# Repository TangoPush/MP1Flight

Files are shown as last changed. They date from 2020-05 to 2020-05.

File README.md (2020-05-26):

# MP1Flight

STM32MP1 based flight controller based off the Pixracer.

Slack channel available here:

https://join.slack.com/t/mp1flight/shared_invite/zt-ewtdxsr4-UjyOhen2aBG~TFt4L_m_wA

Current status:

Still working through developing the first PCB, please contribute at this stage with any features or changes.

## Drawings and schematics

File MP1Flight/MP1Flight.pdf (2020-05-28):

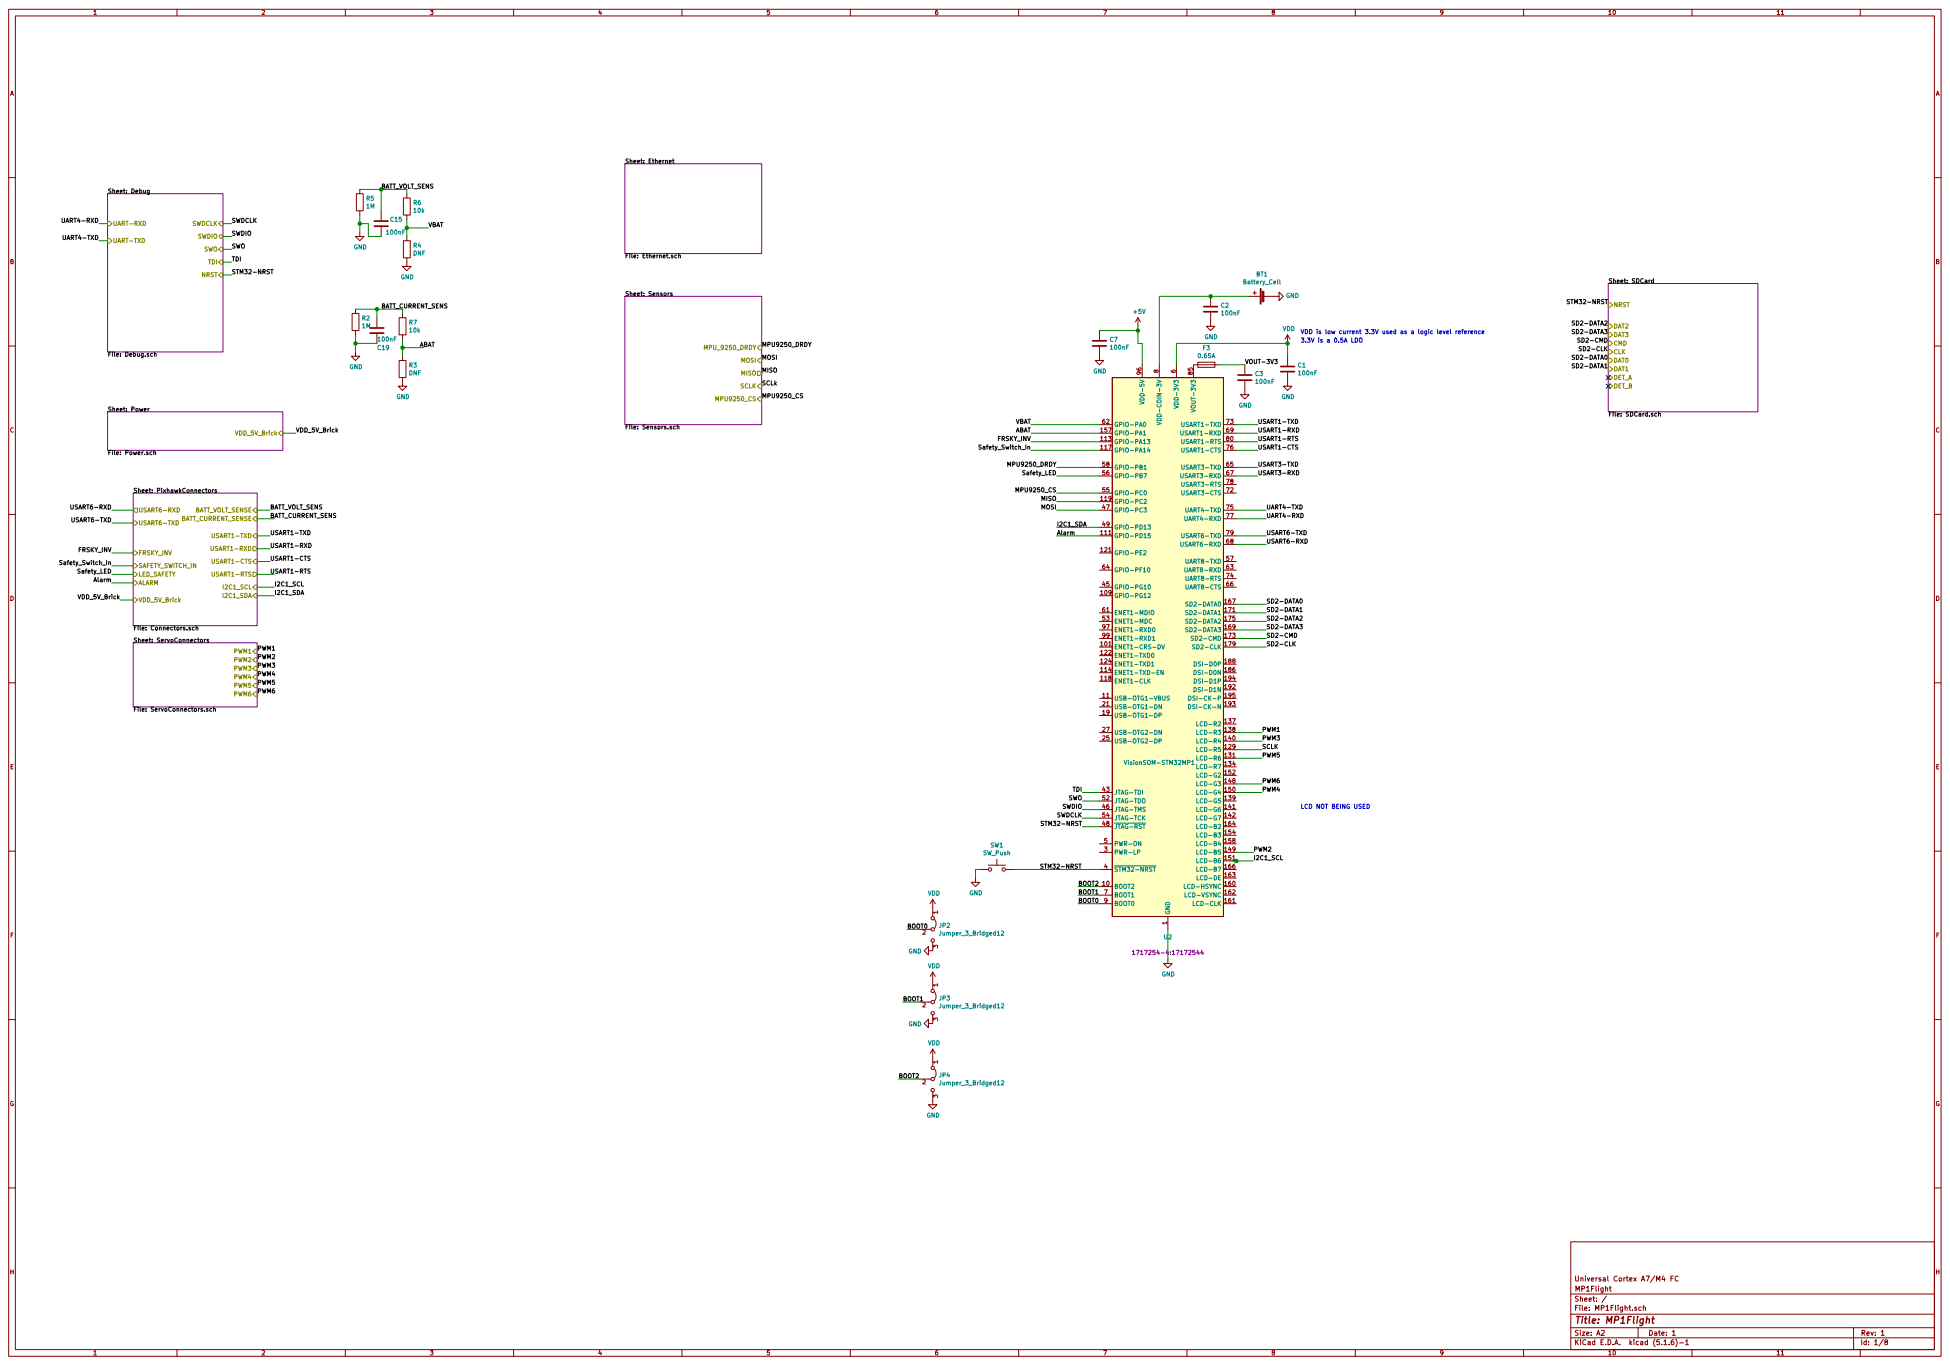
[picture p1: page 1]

TDI NRST UART-RXD

Sheet: SDCard File: SDCard.sch NRST DAT2 DAT3 CMD

1 BOOT2 10 ENET1-CRS-DV 101 GPIO-PG12 109 USB-OTG1-VBUS 11 GPIO-PD15 111 GPIO-PA13 113 ENET1-TXD-EN 114 GPIO-PA14 117 ENET1-CLK 118 GPIO-PC2 119 GPIO-PE2 121 ENET1-TXD0 122 ENET1-TXD1 124

LCD NOT BEING USED

File: MP1Flight.sch Sheet: / MP1Flight Universal Cortex A7/M4 FC

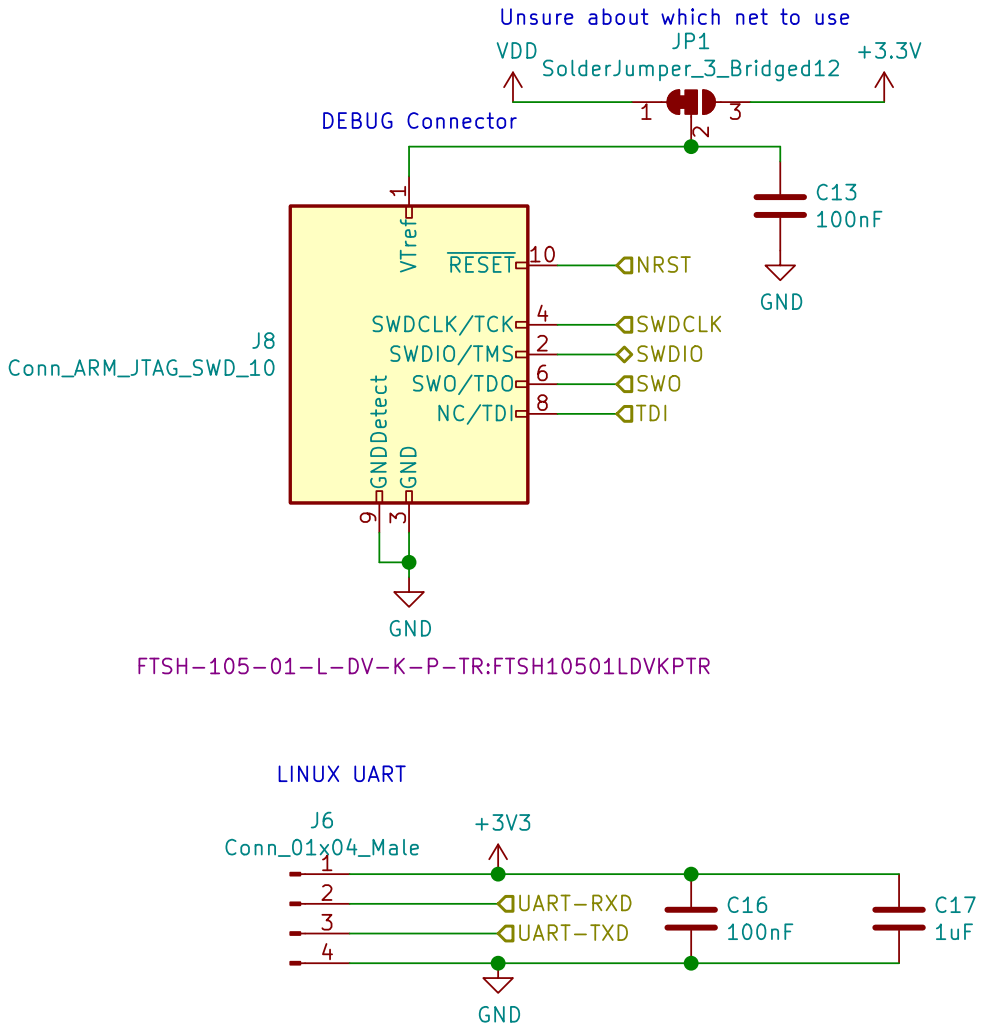
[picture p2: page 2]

VDD
TDI NRST UART-RXD

3 SWDCLK/TCK 4 SWO/TDO 6 NC/TDI 8 GNDDetect 9

MP1Flight
Sheet: /Debug/
File: Debug.sch
Id: 2/8 Title: Contains Debugging connectors for Rev1

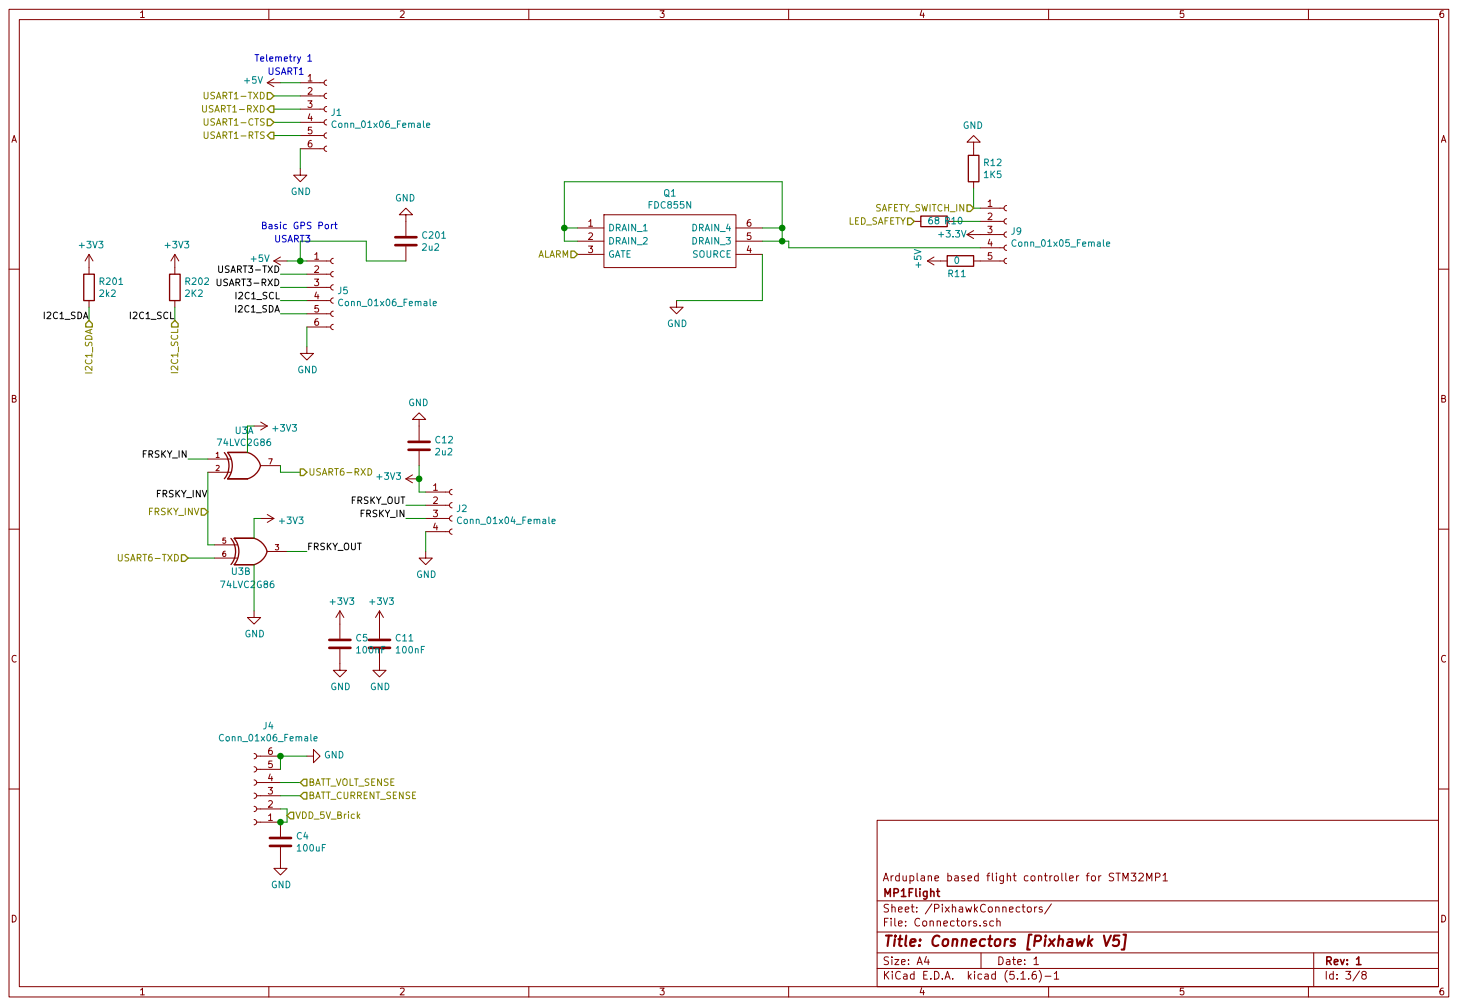
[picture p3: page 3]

Arduplane based flight controller for STM32MP1
Id: 3/8 Title: Connectors [Pixhawk V5] File: Connectors.sch Sheet: /PixhawkConnectors/ MP1Flight

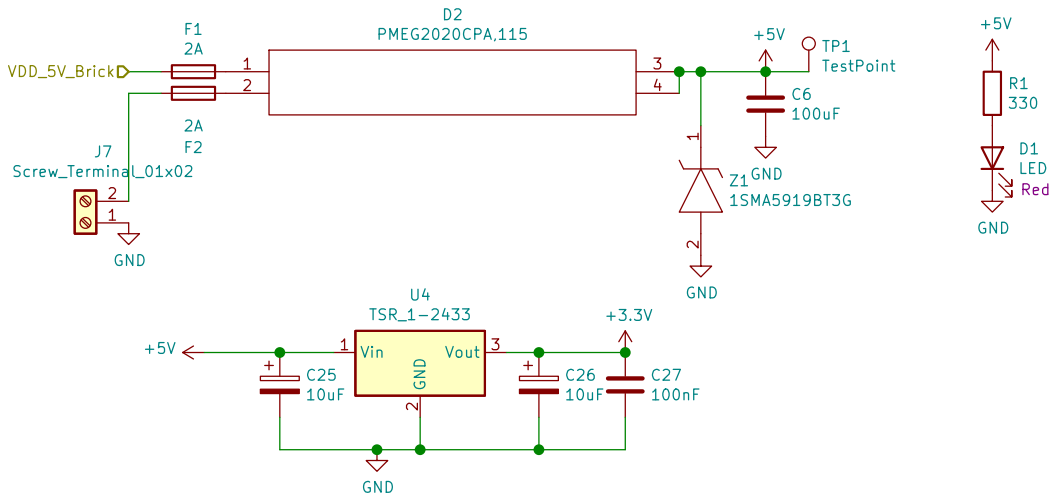
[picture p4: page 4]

File: Power.sch Sheet: /Power/ MP1Flight GND
1SMA5919BT3G

Id: 4/8 Title: Power handling

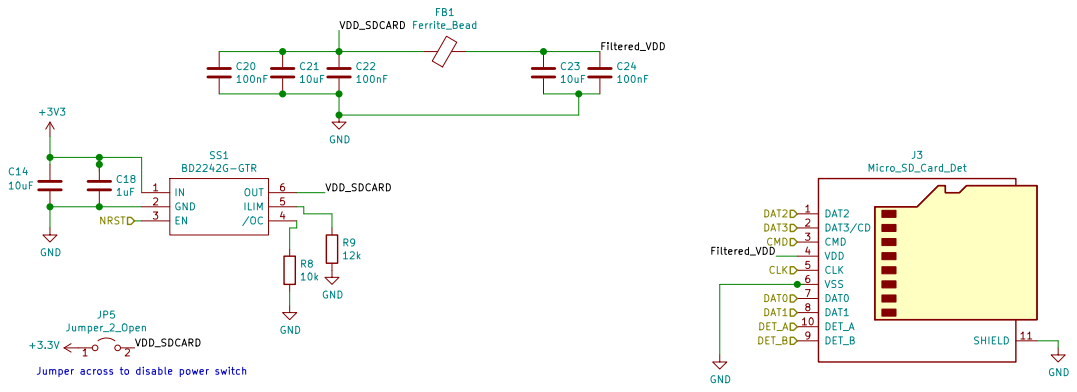
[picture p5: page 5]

File: SDCard.sch Sheet: /SDCard/ MP1Flight R9

Jumper across to disable power switch

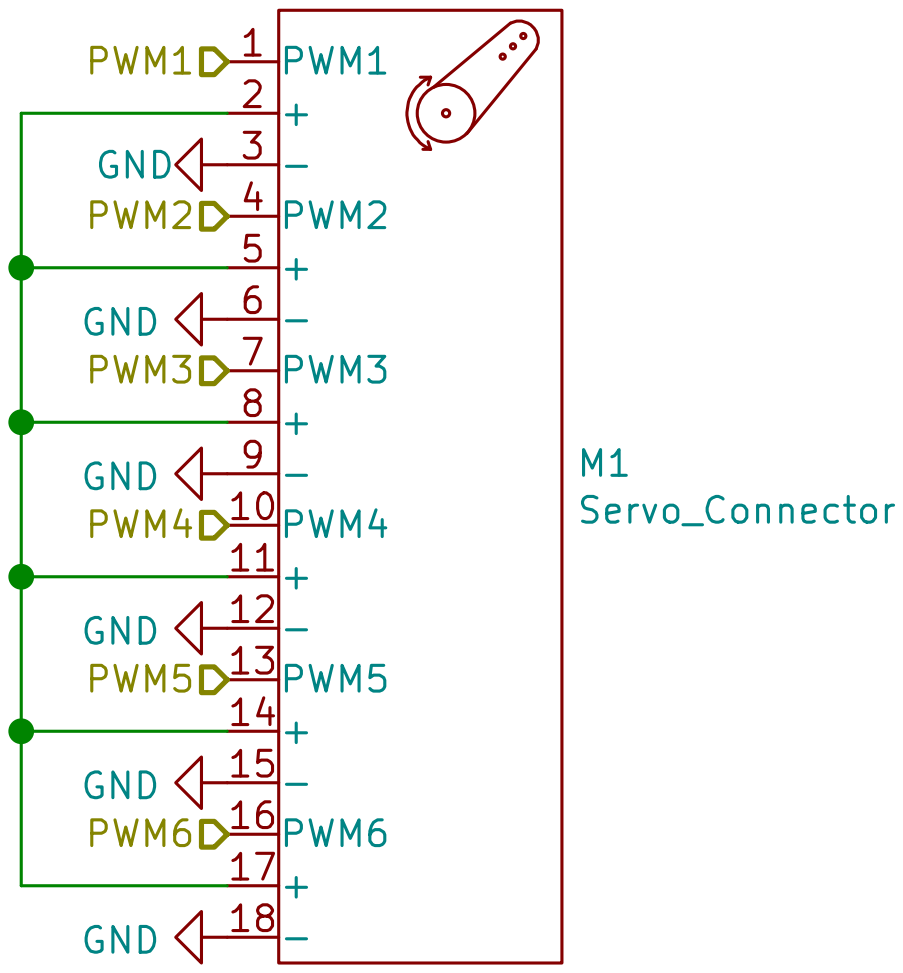
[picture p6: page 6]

PWM6 PWM5 PWM4 PWM3 PWM2 PWM1
GND GND GND GND GND

File: ServoConnectors.sch Sheet: /ServoConnectors/
Id: 6/8 Title: Servo Connectors

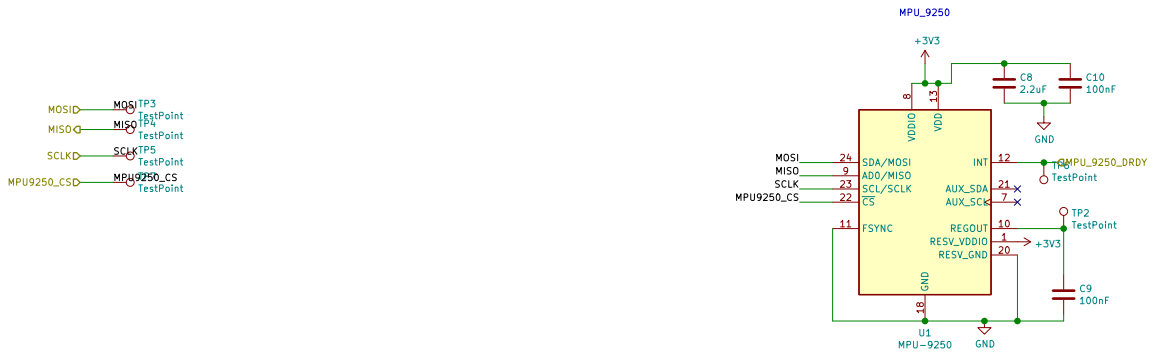
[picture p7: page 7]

Id: 7/8 Title: File: Sensors.sch Sheet: /Sensors/

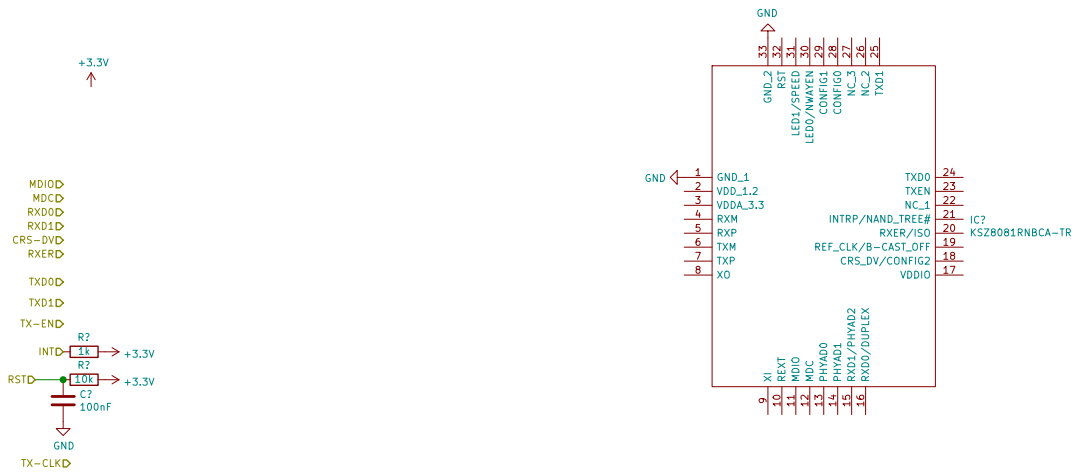
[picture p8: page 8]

CRS-DV RXD1 RXD0 MDC MDIO

Id: 8/8 Title: File: Ethernet.sch Sheet: /Ethernet/ GND

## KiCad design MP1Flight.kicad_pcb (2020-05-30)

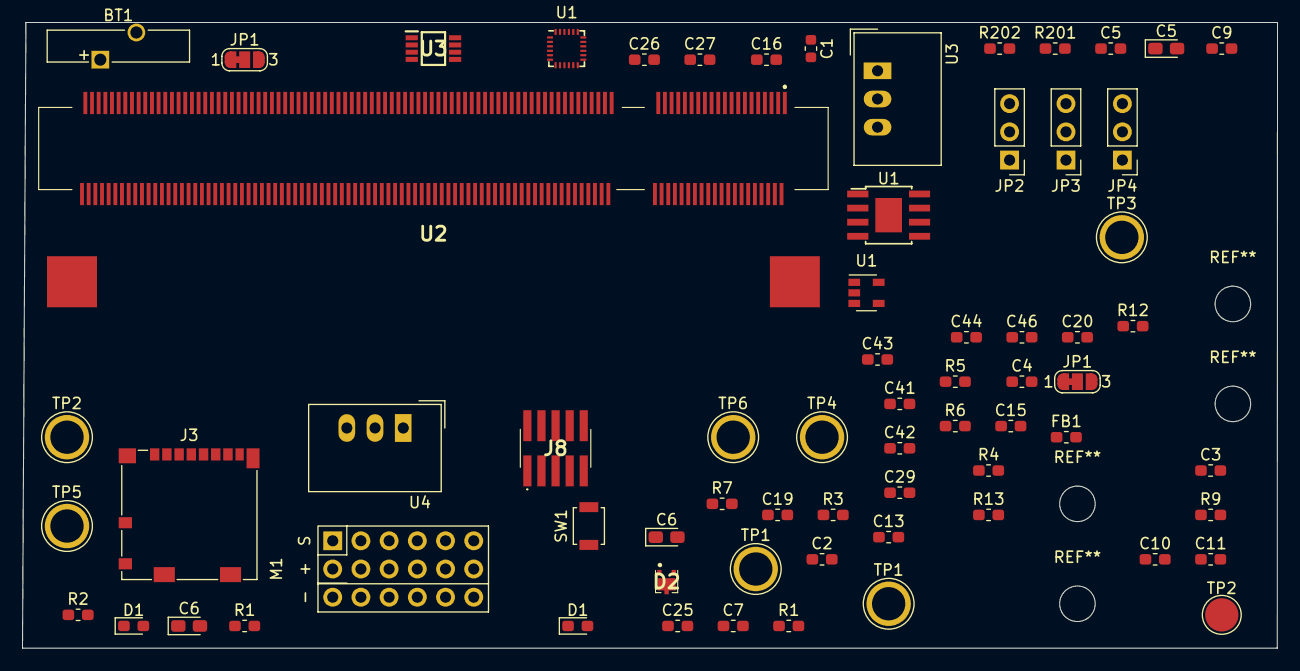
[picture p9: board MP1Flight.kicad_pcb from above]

Board: 2 copper layers, 113.0 x 56.3 mm, 68 parts (0 on the bottom side), 53 nets, no tracks yet.

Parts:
BT1: Battery_Cell; Battery_Panasonic_CR1220-VCN_Vertical_CircularHoles
C1: 100nF; C_0603_1608Metric
C2, C3, C4, C5, C7, C9, C10, C11, C13, C15, C16, C19, C20, C27, C29, C41, C42, C43, C44, C46: 100nF; C_0603_1608Metric_Pad1.05x0.95mm_HandSolder
C5#2: 1uF; CP_EIA-2012-15_AVX-P_Pad1.30x1.05mm_HandSolder
C6: 100uF; CP_EIA-2012-15_AVX-P_Pad1.30x1.05mm_HandSolder
C6#2: 0.1uF; CP_EIA-2012-15_AVX-P_Pad1.30x1.05mm_HandSolder
C25, C26: 10uF; C_0603_1608Metric_Pad1.05x0.95mm_HandSolder
D1, D1#2: LED; LED_0603_1608Metric_Pad1.05x0.95mm_HandSolder
D2: PMEG2020CPA,115; PMEG2020CPA115
FB1: Ferrite_Bead; L_0603_1608Metric_Pad1.05x0.95mm_HandSolder
J3: Micro_SD_Card_Det; microSD_HC_Molex_104031-0811
J8: Conn_ARM_JTAG_SWD_10; FTSH10501LDVKPTR
JP1, JP1#2: SolderJumper_3_Bridged12; SolderJumper-3_P1.3mm_Bridged12_RoundedPad1.0x1.5mm_NumberL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
JP2, JP3, JP4: Jumper_3_Bridged12; PinHeader_1x03_P2.54mm_Vertical
M1: Servo_Connector; 3_6_2_54mm
R1, R1#2: 330; R_0603_1608Metric_Pad1.05x0.95mm_HandSolder
R2, R5: 1M; R_0603_1608Metric_Pad1.05x0.95mm_HandSolder
R3, R4: DNF; R_0603_1608Metric_Pad1.05x0.95mm_HandSolder
R6, R7: 10k; R_0603_1608Metric_Pad1.05x0.95mm_HandSolder
R9: 12k; R_0603_1608Metric_Pad1.05x0.95mm_HandSolder
R12: 1K5; R_0603_1608Metric_Pad1.05x0.95mm_HandSolder
R13: 2k2; C_0603_1608Metric_Pad1.05x0.95mm_HandSolder
R201: 2k2; R_0603_1608Metric_Pad1.05x0.95mm_HandSolder
R202: 2K2; R_0603_1608Metric_Pad1.05x0.95mm_HandSolder
SW1: SW_Push; SW_SPST_B3U-1000P
TP1, TP1#2, TP2, TP3, TP4, TP5, TP6: TestPoint; TestPoint_Plated_Hole_D3.0mm
TP2#2: TestPoint; TestPoint_Pad_D3.0mm
U1: TPS79318-EP; SOT-23-5
U1#2: MPU-9250; InvenSense_QFN-24_3x3mm_P0.4mm
U1#3: ST1S10PHR; TI_SO-PowerPAD-8
U2: VisionSOM-STM32MP1; 17172544
U3: 74LVC2G86; SOP65P400X130-8N
U3#2: TSR_1-2450; Converter_DCDC_TRACO_TSR-1_THT
U4: TSR_1-2433; Converter_DCDC_TRACO_TSR-1_THT

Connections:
+3V3: C5.1, C10.1, C11.1, C16.1, C26.1, C27.1, JP1.3, R201.1, R202.1, U1#2.1, U1#2.8, U1#2.13, U3.8, U4.3
+5V: C6.1, C6#2.1, C7.1, C25.1, D2.3, D2.4, R1.1, R1#2.1, TP1.1, TP1#2.1, U2.96, U2.98, U2.100, U2.102, U2.104, U2.106, U2.108, U2.110, U2.112, U3#2.3, U4.1
/ABAT: R3.1, R7.2, U2.157
/BATT_CURRENT_SENS: C19.1, R2.1, R7.1
/BATT_VOLT_SENS: C15.1, R5.1, R6.1
/BOOT0: JP2.2, U2.9
/BOOT1: JP3.2, U2.7
/BOOT2: JP4.2, U2.10
/FRSKY_INV: U2.113, U3.2, U3.5
/I2C1_SCL: R202.2, U2.151
/I2C1_SDA: R201.2, U2.49
/MISO: TP4.1, U1#2.9, U2.119
/MOSI: TP3.1, U1#2.24, U2.47
/MPU9250_CS: U1#2.22, U2.55
/MPU9250_DRDY: TP6.1, U1#2.12, U2.58
/PWM1: M1.1, U2.138
/PWM2: M1.4, U2.149
/PWM3: M1.7, U2.140
/PWM4: M1.10, U2.150
/PWM5: M1.13, U2.131
/PWM6: M1.16, U2.148
/SCLK: TP5.1, U2.129
/SD2-CLK: J3.5, U2.179
/SD2-CMD: J3.3, U2.173
/SD2-DATA0: J3.7, U2.167
/SD2-DATA1: J3.8, U2.171
/SD2-DATA2: J3.1, U2.175
/SD2-DATA3: J3.2, U2.169
/SDCard/Filtered_VDD: FB1.2, J3.4
/SDCard/VDD_SDCARD: C20.1, FB1.1
/STM32-NRST: J8.10, SW1.2, U2.4, U2.48
/SWDCLK: J8.4, U2.54
/SWDIO: J8.2, U2.46
/SWO: J8.6, U2.52
/Safety_Switch_In: R12.2, U2.117
/Sensors_PowerDomain1/IMU_VDD_1V8: C44.1, C46.1, U1.5
/Sensors_PowerDomain1/VDD_3V3_Sensors: C29.1, C41.1, C42.1, C43.1, U1.1
/TDI: J8.8, U2.43
/USART6-RXD: U2.68, U3.7
/USART6-TXD: U2.79, U3.6
/VBAT: R4.1, R6.2, U2.62
/VIN: C5#2.1, U3#2.1
GND: BT1.2, C1.2, C2.2, C3.2, C4.2, C5.2, C5#2.2, C6.2, C6#2.2, C7.2, C9.2, C10.2, C11.2, C13.2, C15.2, C16.2, C19.2, C20.2, C25.2, C26.2, C27.2, C29.2, C41.2, C42.2, C43.2, C44.2, C46.2, D1.1, D1#2.1, J3.6, J3.11, J8.3, J8.5, J8.9, JP2.3, JP3.3, JP4.3, M1.3, M1.6, M1.9, M1.12, M1.15, M1.18, R2.2, R3.2, R4.2, R5.2, R9.2, R12.1, R13.2, SW1.1, TP2#2.1, U1#2.11, U1#2.18, U1#2.20, U2.1, U2.2, U2.15, U2.17, U2.20, U2.22, U2.23, U2.26, U2.28, U2.29, U2.35, U2.38, U2.40, U2.41, U2.50, U2.51, U2.59, U2.60, U2.70, U2.71, U2.81, U2.82, U2.84, U2.103, U2.107, U2.115, U2.116, U2.120, U2.125, U2.127, U2.128, U2.130, U2.132, U2.133, U2.135, U2.136, U2.143, U2.144, U2.145, U2.146, U2.147, U2.153, U2.155, U2.156, U2.159, U2.165, U2.168, U2.170, U2.172, U2.174, U2.176, U2.177, U2.178, U2.180, U2.181, U2.182, U2.184, U2.185, U2.189, U2.199, U2.200, U3.4, U3#2.2, U4.2
unnamed: BT1.1, C2.1, U2.8
unnamed: C4.1, JP1#2.2
unnamed: C9.1, TP2.1, U1#2.10
unnamed: C13.1, J8.1, JP1.2
unnamed: D1.2, D1#2.2, R1.2, R1#2.2
unnamed: U2.85, U2.87, U2.88, U2.89, U2.90, U2.91, U2.92, U2.93
unnamed: M1.2, M1.5, M1.8, M1.11, M1.14, M1.17
unnamed: U1.2, U1#3.2
unnamed: U1#2.7, U1#3.7
VDD: C1.1, JP1.1, JP2.1, JP3.1, JP4.1, U2.6

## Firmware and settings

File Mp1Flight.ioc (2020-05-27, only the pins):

Mcu.UserName=STM32MP157AABx
PA0.GPIO_Label=VBAT
PA0.Signal=ADC1_INP16
PA1.GPIO_Label=ABAT
PA1.Signal=ADC1_INN16
PA10.Signal=USART1_RX
PA11.Signal=USART1_CTS
PA12.Signal=USART1_RTS
PA13.GPIO_Label=FRSKY_INV
PA13.Signal=GPIO_Output
PA14.GPIO_Label=Safety_Switch_In
PA14.Signal=GPIO_Input
PA15.Signal=SDMMC1_D5
PA2.Signal=ETH1_MDIO
PA3.GPIO_Label=PWM2
PA3.Signal=S_TIM2_CH4
PA5.GPIO_Label=PWM3
PA5.Signal=S_TIM2_CH1
PA7.Signal=ETH1_CRS_DV
PA8.GPIO_Label=PWM5
PA8.Signal=S_TIM1_CH1
PA9.Signal=SPI2_SCK
PB0.GPIO_Label=PWM1
PB0.Signal=S_TIM3_CH3
PB1.Signal=ADCx_INP5
PB10.GPIO_Label=PWM4
PB10.Signal=S_TIM2_CH3
PB11.Signal=ETH1_TX_EN
PB13.Signal=ETH1_TXD1
PB14.Signal=SDMMC2_D0
PB15.Signal=SDMMC2_D1
PB2.Signal=UART4_RX
PB3.Signal=SDMMC2_D2
PB4.Signal=SDMMC2_D3
PB5.Signal=ETH1_CLK
PB6.Signal=USART1_TX
PB7.GPIO_Label=Safety_LED
PB7.Signal=GPIO_Output
PB8.Signal=I2C1_SCL
PB9.Signal=LTDC_B7
PC0.GPIO_Label=MPU9250_CS
PC0.Signal=GPIO_Output
PC1.Signal=ETH1_MDC
PC11.Signal=SDMMC1_D3
PC12.Signal=SDMMC1_CK
PC13.Signal=RTC_LSCO
PC14-OSC32_IN.Signal=RCC_OSC32_IN
PC15-OSC32_OUT.Signal=RCC_OSC32_OUT
PC2.Signal=SPI2_MISO
PC3.Signal=SPI2_MOSI
PC4.Signal=ETH1_RXD0
PC5.Signal=ETH1_RXD1
PC8.Signal=SDMMC1_D0
PC9.Signal=SDMMC1_D1
PD0.Signal=SDMMC3_CMD
PD1.Signal=SDMMC3_D0
PD11.Signal=USART3_CTS
PD12.Signal=USART3_RTS
PD13.Signal=I2C1_SDA
PD14.Signal=UART8_CTS
PD15.Signal=S_TIM4_CH4
PD2.Signal=SDMMC1_CMD
PD3.Signal=SDMMC1_D7
PD4.Signal=SDMMC3_D1
PD5.Signal=SDMMC3_D2
PD7.Signal=SDMMC3_D3
PD8.Signal=USART3_TX
PD9.Signal=USART3_RX
PE0.Signal=UART8_RX
PE1.Signal=UART8_TX
PE10.Signal=UART7_CTS
PE11.GPIO_Label=PWM6
PE11.Signal=S_TIM1_CH2
PE14.Signal=LTDC_CLK
PE3.Signal=SDMMC2_CK
PE4.Signal=SDMMC1_D4
PE5.Signal=SDMMC1_D6
PE6.Signal=SDMMC1_D2
PE7.Signal=UART7_RX
PE8.Signal=UART7_TX
PF8.Signal=UART7_RTS
PG11.Signal=UART4_TX
PG13.Signal=ETH1_TXD0
PG14.Signal=USART6_TX
PG15.Signal=SDMMC3_CK
PG6.Signal=SDMMC2_CMD
PG7.Signal=UART8_RTS
PG8.Signal=LTDC_G7
PG9.Signal=USART6_RX
PH0-OSC_IN.Signal=RCC_OSC_IN

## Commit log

2020-05-25 Initial commit: Completed significant portion of the schematic
    [MP1Flight.kicad_pcb, MP1Flight.sch]
2020-05-25 adding in SD card with power switch
    [MP1Flight.sch]
2020-05-26 Moved connectors to child sheet
    [Connectors.sch, Debug.sch, MP1Flight.sch]
2020-05-26 Updated sheet titles
    [Connectors.sch, Debug.sch, MP1Flight.sch]
2020-05-26 Added in Debug sheet
    [Debug.sch, MP1Flight.sch]
2020-05-26 Added in SD Card Sheet plus made SD card connections
    [Connectors.sch, Debug.sch, MP1Flight.sch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]
2020-05-26 Added in Servo Outputs and Setup the timers in CubeMX
    [Connectors.sch, Debug.sch, MP1Flight.sch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]
2020-05-27 Added in Buzzer and N channel mosfet
    [Connectors.sch, MP1Flight.kicad_pcb, MP1Flight.sch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]
2020-05-27 Safety LED, Alarm and Safety switch additions
    [MP1Flight.sch]
2020-05-28 IMU1/2 added in plus regs
    [Connectors.sch, Debug.sch, Ethernet.sch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]
2020-05-30 Added in Magnetometer and barometer
    [Sensors.sch]
2020-05-30 Wired up IMUs signals
    [Debug.sch, MP1Flight.kicad_pcb, MP1Flight.sch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]
